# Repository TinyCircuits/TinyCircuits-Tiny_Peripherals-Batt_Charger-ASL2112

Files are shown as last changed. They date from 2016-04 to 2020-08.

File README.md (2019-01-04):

# TinyCircuits Tiny Peripheral Battery Charger
# ASL2112 Rev2

The design files are located under design_files/ for the TinyCircuits ASL2112 Rev 2 PCB.  This is a Tiny peripheral board that has a Lithium battery charger and JST SH connector.

Format is in Cadsoft Eagle format - Eagle version 6.2 was used for the original design.

For more infomation on this, check out the product page at TinyCircuits.com: https://tinycircuits.com/collections/accessories/products/tiny-battery-charger

# License:

Design by TinyCircuits.
All design files are released under the Creative Commons Attribution Share-Alike 3.0 License, see the following link for details: http://creativecommons.org/licenses/by-sa/3.0

All text above must be included in any redistribution or derived design

This project uses designs and concepts developed as part of the Arduino project and the LilyPad project.  The TinyCircuits design files themselves (schematics, PCB and libraries) are not directly derived from these works' design files and have been created new, however the concepts and basic architecture behind the TinyDuino and TinyLily products are derived and we thank the hard work of the organizations below for their contributions to open-source hardware:
  
Original Arduino Uno Design by Team Arduino

LilyPad Arduino Design by Leah Buechley and Sparkfun Electronics

Please support the open-source hardware community

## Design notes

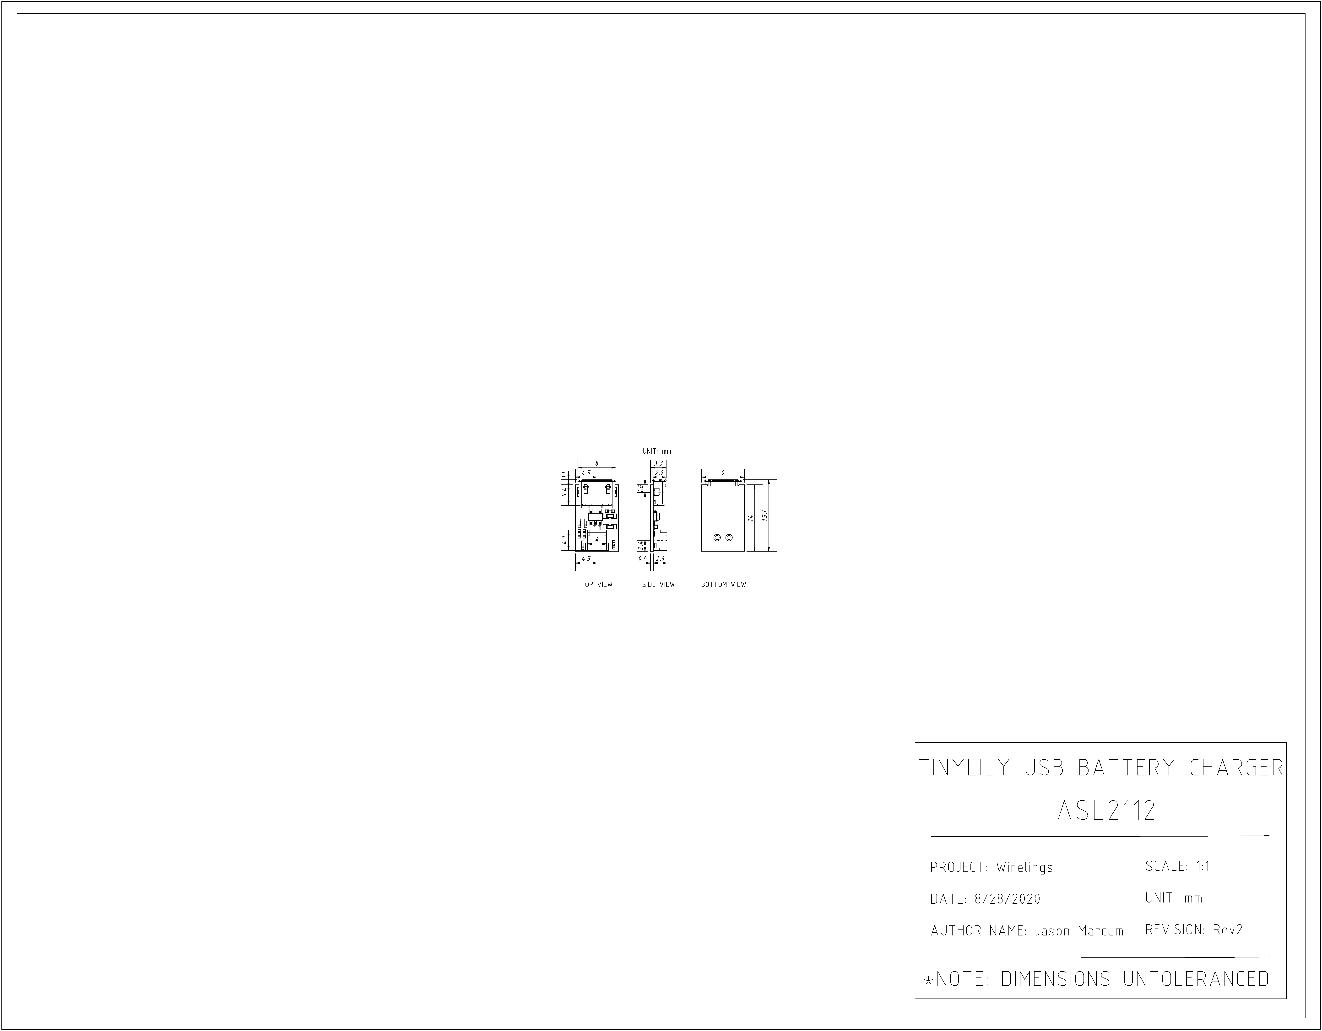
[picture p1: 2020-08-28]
cad/TinyLily_CHARGER_ASL2112_REV2-DETAILED_DRAWING-PNG.png

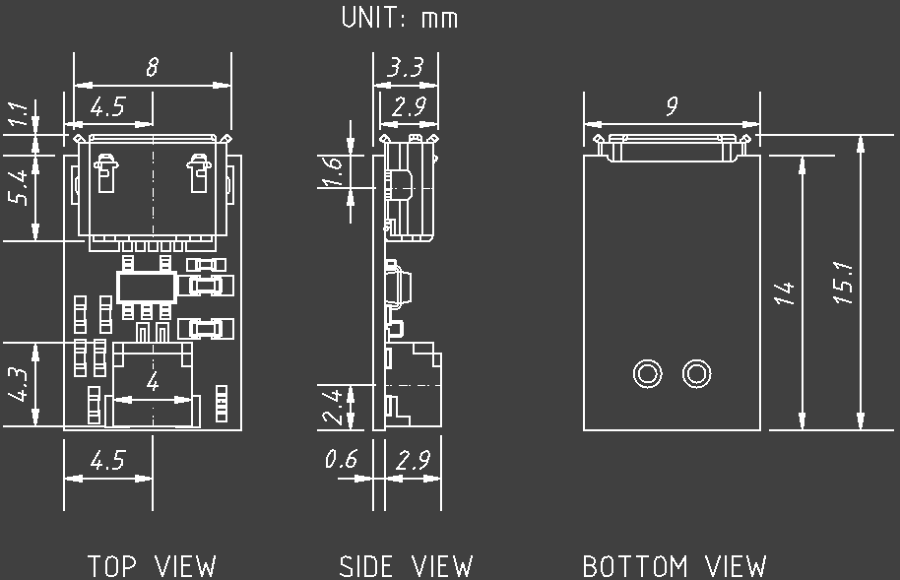
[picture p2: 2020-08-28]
cad/TinyLily_CHARGER_ASL2112_REV2-DETAILED_DRAWING_COMPACT-PNG.png

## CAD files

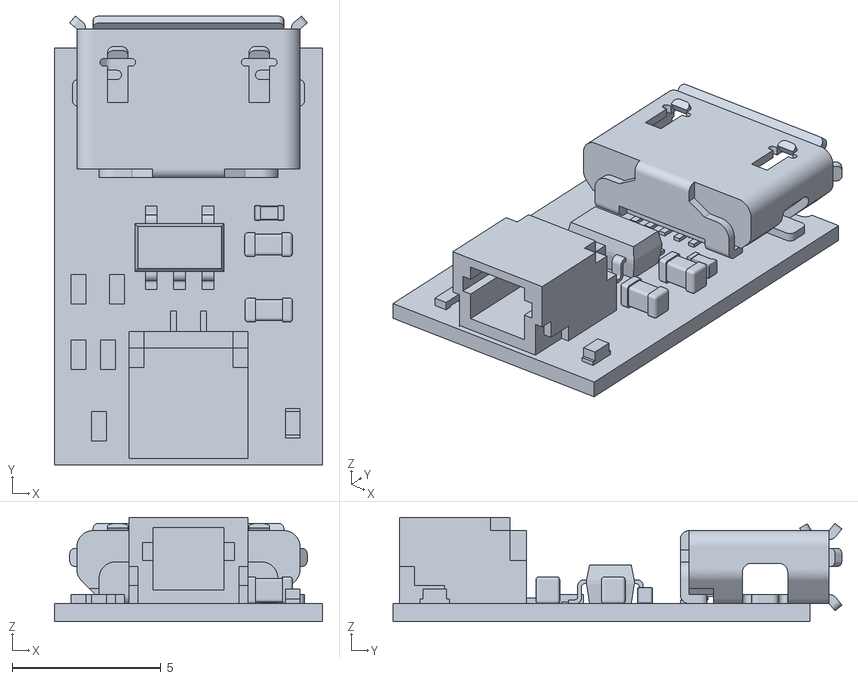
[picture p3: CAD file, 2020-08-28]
cad/TinyLily_CHARGER_ASL2112_REV2-STL.stl
9.00 x 15.1 x 3.50

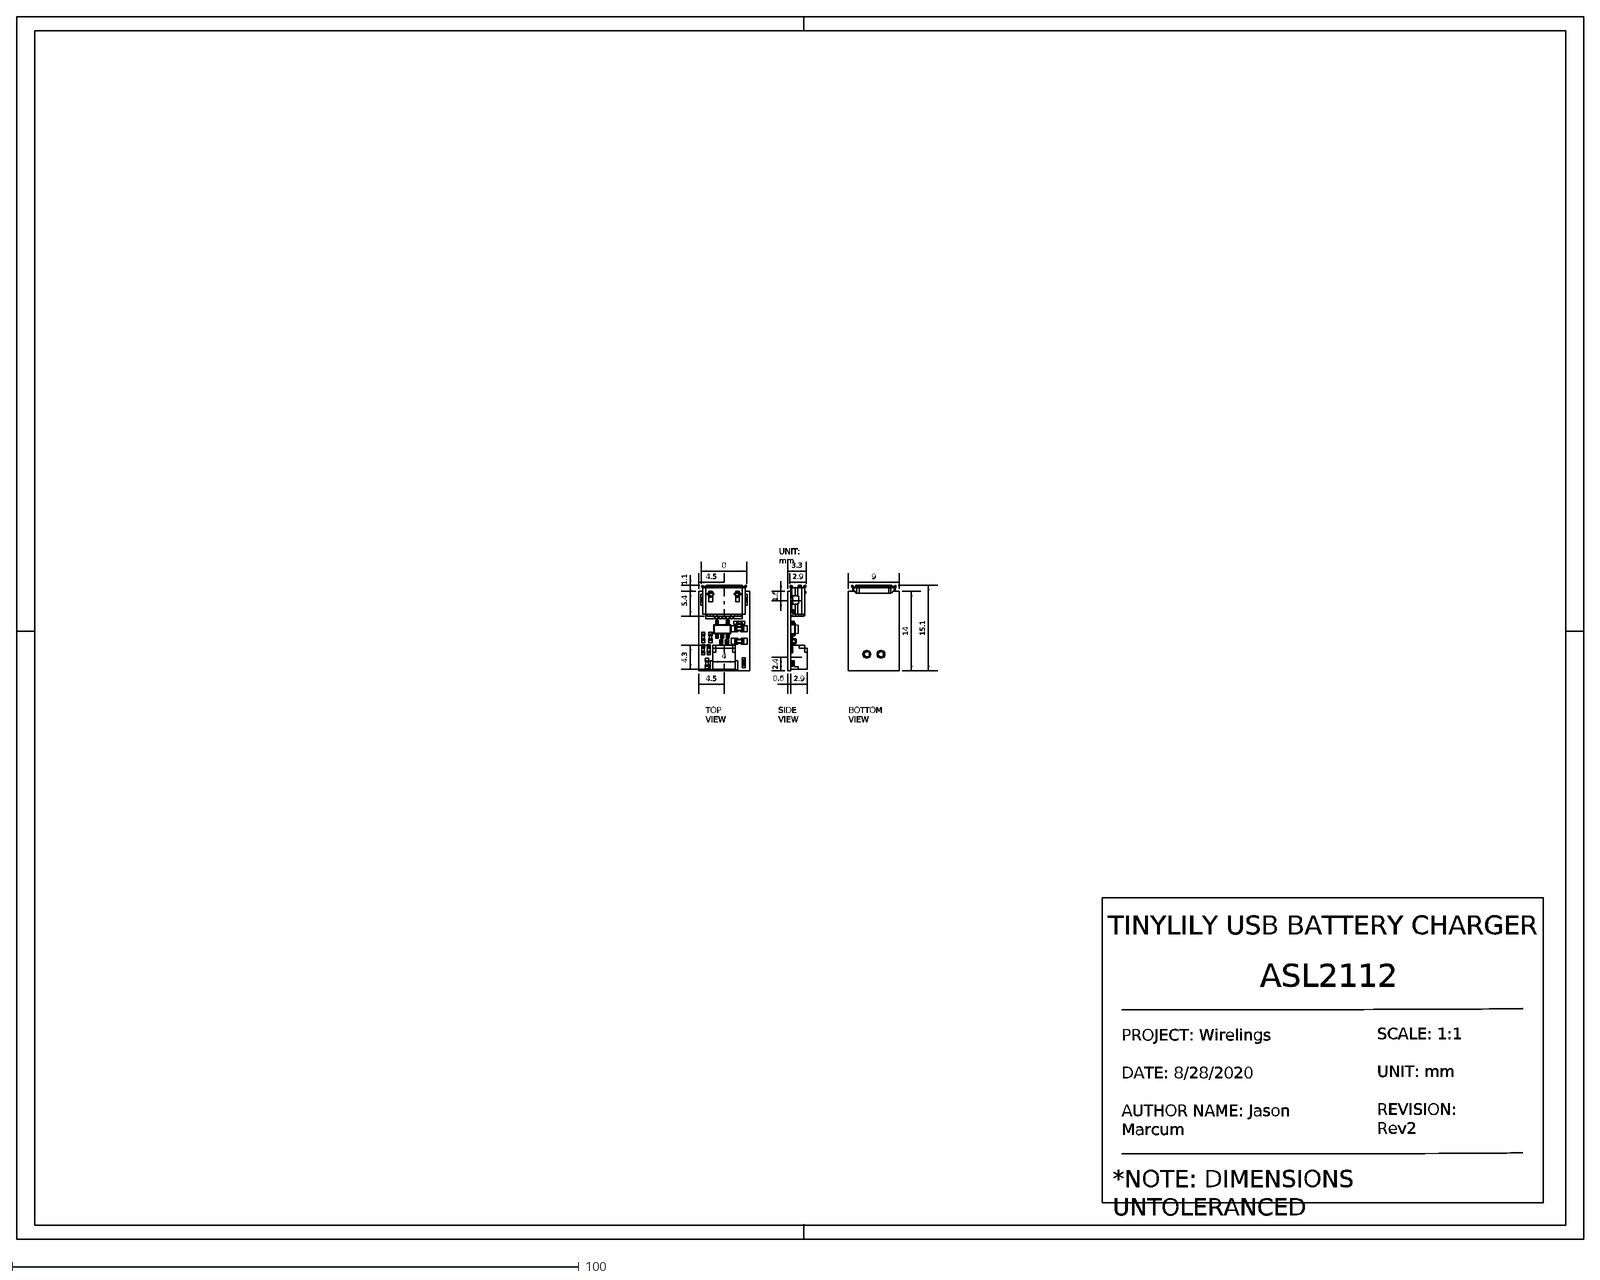
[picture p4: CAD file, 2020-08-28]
cad/TinyLily_CHARGER_ASL2112_REV2-DETAILED_DRAWING-DXF.dxf
*NOTE: DIMENSIONS UNTOLERANCED
TOP VIEW
BOTTOM VIEW
SIDE VIEW
2.4
1.6
4.5
8
5.4
4.3
4
2.9
3.3
UNIT: mm
0.6
9
14
15.1
1.1
TINYLILY USB BATTERY CHARGER
ASL2112
PROJECT: Wirelings DATE: 8/28/2020 AUTHOR NAME: Jason Marcum
SCALE: 1:1 UNIT: mm REVISION: Rev2

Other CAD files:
cad/TinyLily_CHARGER_ASL2112_REV2-IGES.iges

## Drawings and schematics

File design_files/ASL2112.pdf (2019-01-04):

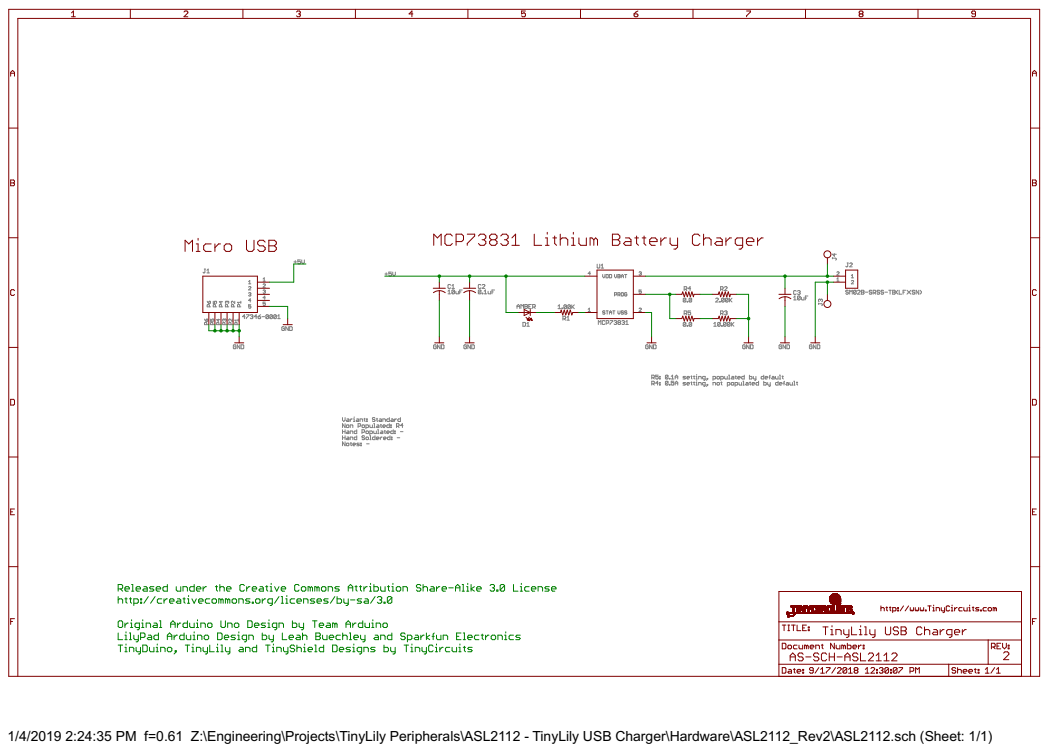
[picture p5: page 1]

1/4/2019 2:24:35 PM f=0.61 Z:\Engineering\Projects\TinyLily Peripherals\ASL2112 - TinyLily USB Charger\Hardware\ASL2112_Rev2\ASL2112.sch (Sheet: 1/1)

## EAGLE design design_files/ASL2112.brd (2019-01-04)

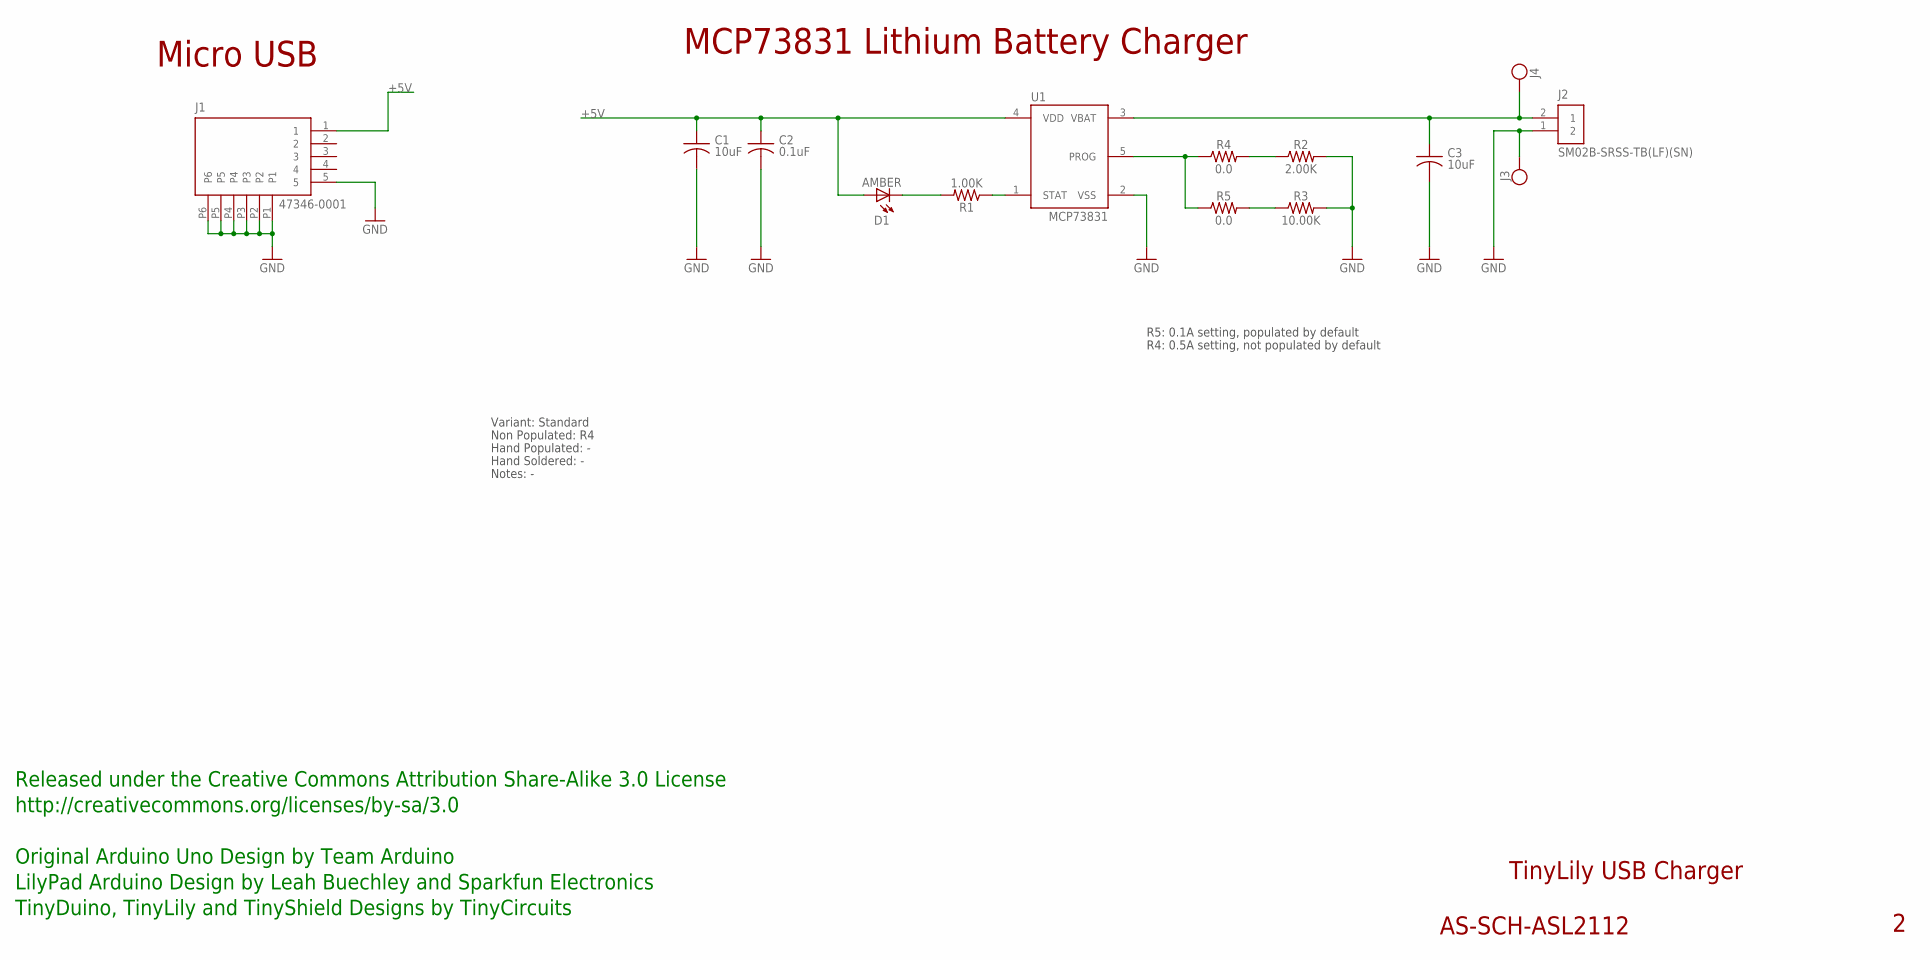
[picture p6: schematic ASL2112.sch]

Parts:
C1: 10uF; C0603
C2: 0.1uF; C0402
C3: 10uF; C0603; PARTNO AS-ITM-00002
D1: AMBER; 0402_LED; PARTNO AS-ITM-00058
J1: 47346-0001; MICRO_USB; PARTNO AS-ITM-00021
J2: SM02B-SRSS-TB(LF)(SN); JST_SH_2X1
J3, J4: PIN_1X.1"1; 1X.1"_2
R1: 1.00K; 0402
R2: 2.00K; 0402; PARTNO AS-ITM-00315
R3: 10.00K; 0402; PARTNO AS-ITM-00032
R4, R5: 0.0; 0402
U1: MCP73831; SOT-23

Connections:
+5V: C1.1, C2.1, D1.1 (A), J1.1, U1.4 (VDD)
GND: C1.2, C2.2, C3.2, J1.5, J1.P1, J1.P2, J1.P3, J1.P4, J1.P5, J1.P6, J2.1 (2), J3.1, R2.2, R3.2, U1.2 (VSS)
unnamed: R1.1, U1.1 (STAT)
unnamed: D1.2 (C), R1.2
unnamed: R4.1, R5.1, U1.5 (PROG)
unnamed: R2.1, R4.2
unnamed: C3.1, J2.2 (1), J4.1, U1.3 (VBAT)
unnamed: R3.1, R5.2

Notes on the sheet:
TinyLily USB Charger
AS-SCH-ASL2112
Micro USB
MCP73831 Lithium Battery Charger
Released under the Creative Commons Attribution Share-Alike 3.0 License
http://creativecommons.org/licenses/by-sa/3.0
Original Arduino Uno Design by Team Arduino
TinyDuino, TinyLily and TinyShield Designs by TinyCircuits
LilyPad Arduino Design by Leah Buechley and Sparkfun Electronics
R5: 0.1A setting, populated by default
Non Populated: R4
Hand Populated: -
Hand Soldered: -
Notes: -
Variant: Standard
R4: 0.5A setting, not populated by default

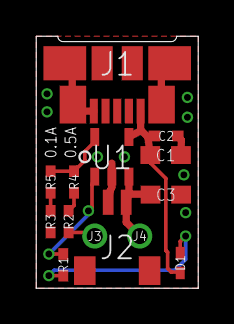
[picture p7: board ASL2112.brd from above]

Board: 2 copper layers, 9.0 x 14.0 mm, 15 parts (0 on the bottom side), 8 nets.

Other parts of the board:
U$1: DOCFIELD-TINYCIRCUITS-PCB

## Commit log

2016-04-26 Initial Commit
    Initial Commit
    [ASL2112.brd, ASL2112.sch]
2019-01-04 update format
    [ASL2112.brd, ASL2112.sch]
2020-08-28 Add CAD data
    [TinyLily_CHARGER_ASL2112_REV2-DETAILED_DRAWING-DXF.dxf, TinyLily_CHARGER_ASL2112_REV2-IGES.iges, TinyLily_CHARGER_ASL2112_REV2-STL.stl]
